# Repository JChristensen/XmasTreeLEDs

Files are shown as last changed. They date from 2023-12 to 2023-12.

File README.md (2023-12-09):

# Xmas Tree LEDs
https://github.com/JChristensen/XmasTreeLEDs  
README file  
Jack Christensen  
Nov-2023

## License
  
Xmas Tree LEDs by Jack Christensen is licensed under a [Creative Commons Attribution-ShareAlike 4.0 International License](http://creativecommons.org/licenses/by-sa/4.0/).

## Overview
Blinkenlights for a small ceramic Christmas Tree. Uses an ATTiny84A microcontroller and a boost regulator to maintain constant voltage to the circuit. Battery is two AAA cells and fits under the base.

See the [firmware here](https://github.com/JChristensen/XmasTree).  
PC boards can be ordered from [OSH Park](https://oshpark.com/shared_projects/T9Cb02lh).  
A bill of materials is available at [Mouser Electronics](https://www.mouser.com/ProjectManager/ProjectDetail.aspx?AccessID=e903af6094) and also in this repo.  

https://github.com/JChristensen/XmasTreeLEDs/assets/762571/b531e305-ae8b-4c04-a3d2-77f9e12bad94

https://github.com/JChristensen/XmasTreeLEDs/assets/762571/8232f8c4-e6b6-4896-a1eb-c29be3a8e65b

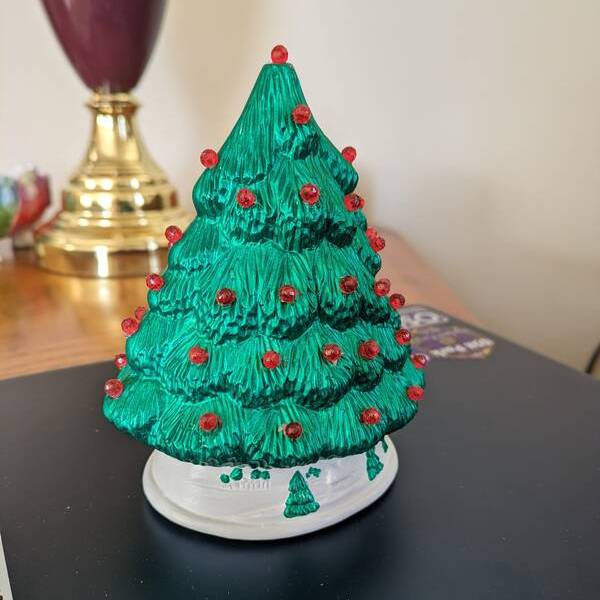
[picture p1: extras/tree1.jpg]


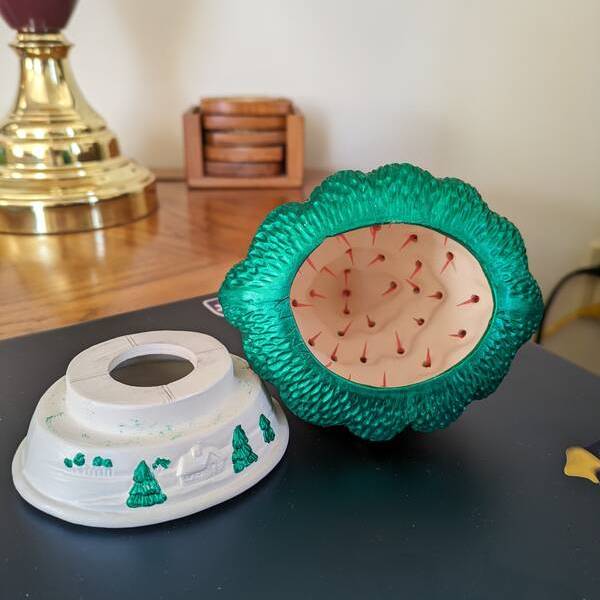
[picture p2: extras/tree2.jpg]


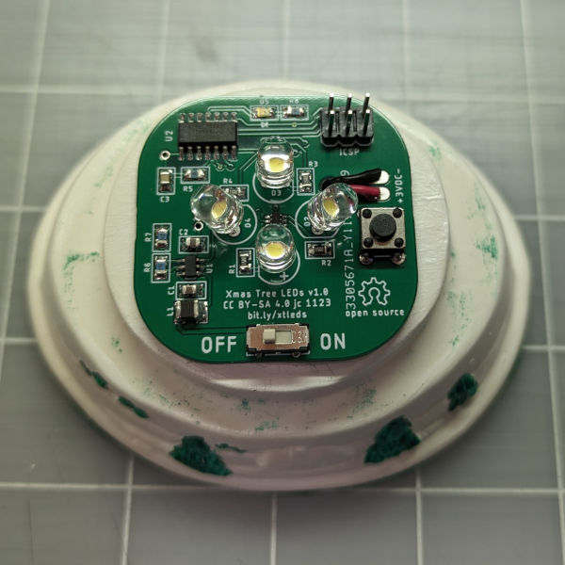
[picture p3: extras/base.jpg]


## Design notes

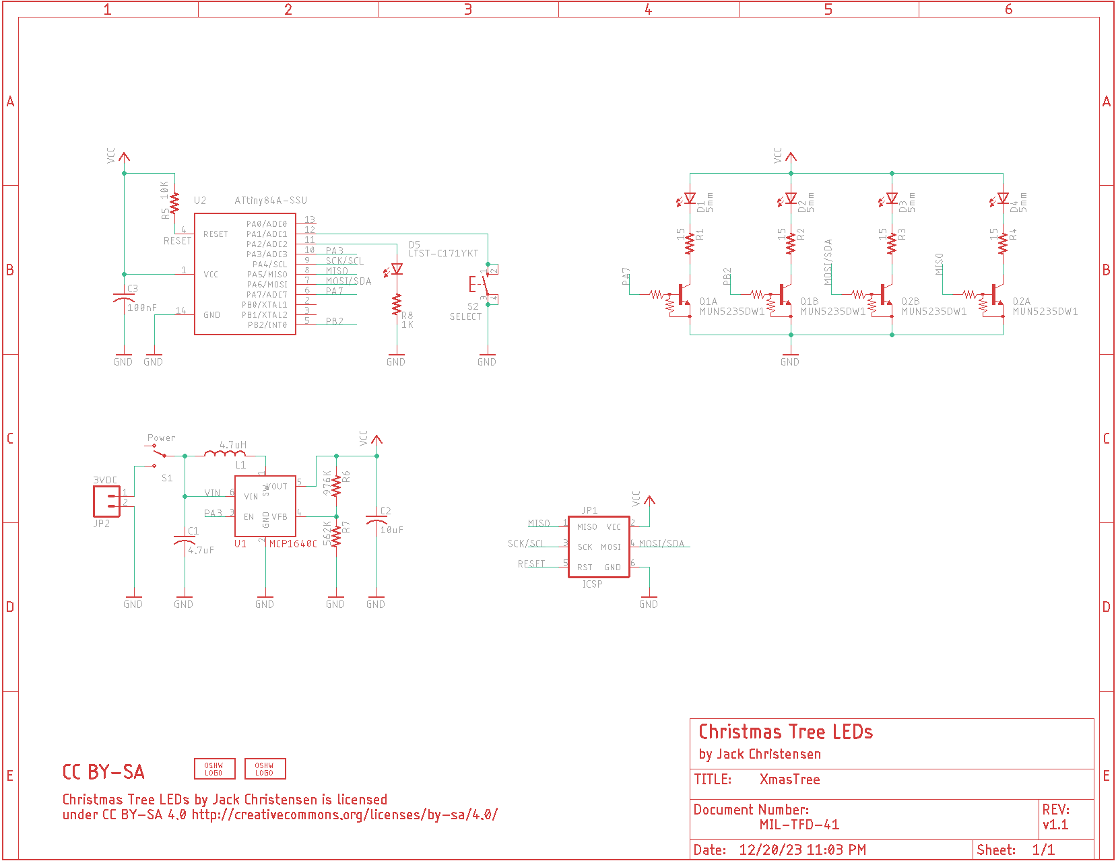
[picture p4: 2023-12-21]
schematic.png

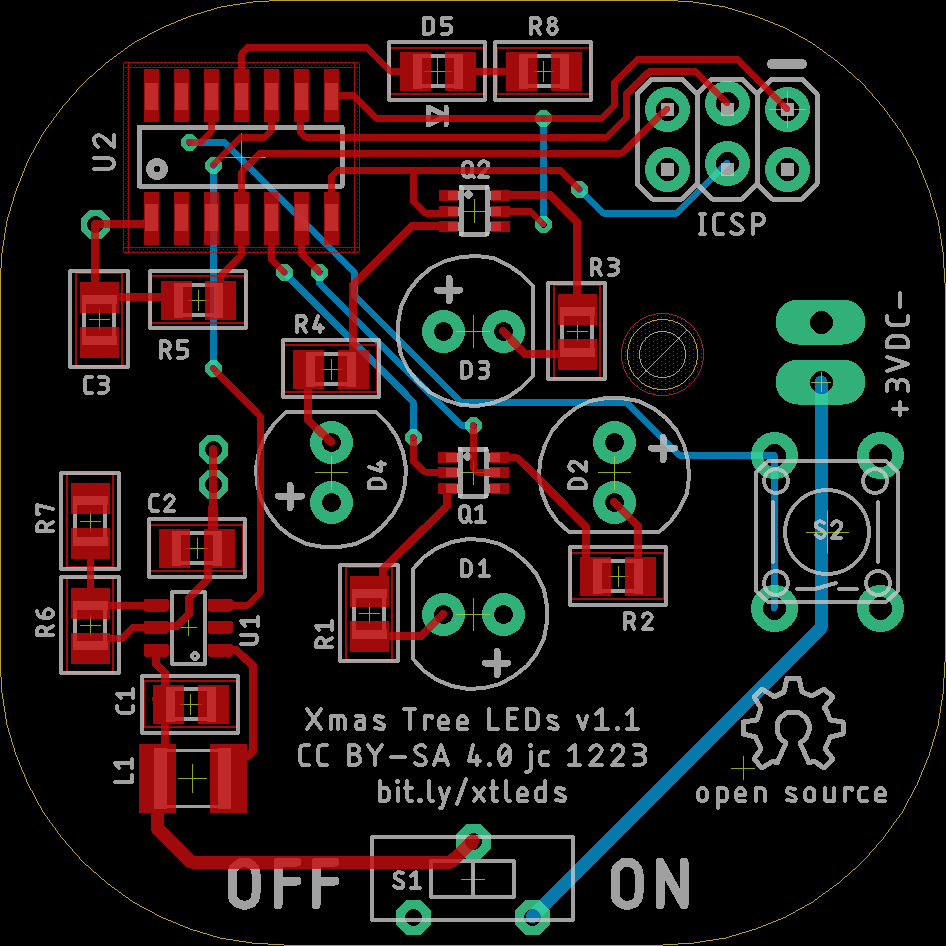
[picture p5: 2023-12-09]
board.png

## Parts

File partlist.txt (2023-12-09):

Partlist

Exported from XmasTree.sch at 12/9/23 4:06 PM

EAGLE Version 9.6.2 Copyright (c) 1988-2020 Autodesk, Inc.

Assembly variant: 

Part     Value          Device                Package        Library  Sheet

B1       2xAAA          Keystone 2489         n/a            n/a      1
C1       4.7uF          C-USM0805             M0805          _jc      1
C2       10uF           C-USM0805             M0805          _jc      1
C3       100nF          C-USM0805             M0805          _jc      1
D1       5mm            LED5MM                LED5MM         _jc      1
D2       5mm            LED5MM                LED5MM         _jc      1
D3       5mm            LED5MM                LED5MM         _jc      1
D4       5mm            LED5MM                LED5MM         _jc      1
D5       LTST-C171YKT   LEDD0805              D0805          _jc      1
JP1      ICSP           AVR_SPI_PRG_62X3_LOCK 2X3_LOCK       _jc      1
JP2      3VDC           M02                   1X02_LONGPADS  SparkFun 1
L1       4.7uH          INDUCTORC1210K        C1210K         _jc      1
Q1       MUN5235DW1T1G  MUN52XXSOT363         SOT363_PHILIPS _jc      1
Q2       MUN5235DW1T1G  MUN52XXSOT363         SOT363_PHILIPS _jc      1
R1       15             R-US_M0805            M0805          _jc      1
R2       15             R-US_M0805            M0805          _jc      1
R3       15             R-US_M0805            M0805          _jc      1
R4       15             R-US_M0805            M0805          _jc      1
R5       10K            R-US_M0805            M0805          _jc      1
R6       976K           R-US_M0805            M0805          _jc      1
R7       562K           R-US_M0805            M0805          _jc      1
R8       1K             R-US_M0805            M0805          _jc      1
S1       Power          SWITCH-SPST           JS102011CQN    SparkFun 1
S2       SELECT         10-XXOCT              B3F-10XXOCT    _jc      1
U1       MCP1640C       MCP1640               SOT23-6        _jc      1
U2       ATtiny84A-SSU  ATTINYX4SO14          SO14           _jc      1

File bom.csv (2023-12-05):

Bill of Materials
Xmas Tree LEDs
by Jack Christensen
Nov-2023
https://www.mouser.com/ProjectManager/ProjectDetail.aspx?AccessID=e903af6094
Part | Qty | Mouser # | Description | Mfr. # | Manufacturer
B1 | 1 | 534-2489 | Cylindrical Battery Contacts, Clips, Holders & Springs 2 AAA cell holder Densi-Pak | 2489 | Keystone Electronics
C1 | 1 | 187-CL21A475KPFNNNE | Multilayer Ceramic Capacitors MLCC - SMD/SMT 4.7uF+/-10% 10V X5R 0805 | CL21A475KPFNNNE | Samsung Electro-Mechanics
C2 | 1 | 187-CL21A106KPCLQNC | Multilayer Ceramic Capacitors MLCC - SMD/SMT 10uF+/-10% 10V X5R 2 0805 | CL21A106KPCLQNC | Samsung Electro-Mechanics
C3 | 1 | 581-08053C104KAT4A | Multilayer Ceramic Capacitors MLCC – SMD/SMT 25V 0.1uF X7R 0805 10% | 08053C104KAT4A | KYOCERA AVX
D1-D4 | 4 | 941-C513AWSNCX0Z0342 | Standard LEDs - Through Hole White | C513A-WSN-CX0Z0342 | Cree LED
D5 | 1 | 859-LTST-C171YKT | Standard LEDs - SMD Yellow Clear 588nm | LTST-C171YKT | Lite-On
JP1 | 1 | 474-PRT-12807 | Header - 2x3 (Male, 0.1") | PRT-12807 | SparkFun Electronics
JP2 | 0 | Board footprint only | Solder pads | n/a | n/a
L1 | 1 | 963-CBC3225T4R7MR | Power Inductors - SMD 1210 4.7uH 130mOhms +/-20% 1010mA HiCur | CBC3225T4R7MR | TAIYO YUDEN
Q1-Q2 | 2 | 863-MUN5235DW1T1G | Bipolar Transistors - Pre-Biased 100mA 50V BRT Dual NPN | MUN5235DW1T1G | onsemi
R1-R4 | 4 | 660-RK73H2ATTD15R0F | Thick Film Resistors - SMD 1/4W 15 OHM 1% | RK73H2ATTD15R0F | KOA Speer
R5 | 1 | 660-RK73H1JTTDD1002F | Thick Film Resistors - SMD 1/10watts 10Kohms 1% | RK73H1JTTDD1002F | KOA Speer
R6 | 1 | 660-RK73H1ETTP9763F | Thick Film Resistors - SMD 0.1watt 976Kohms 1% | RK73H1ETTP9763F | KOA Speer
R7 | 1 | 660-RK73H2ATTD5623F | Thick Film Resistors - SMD 1/4W 562K OHM 1% | RK73H2ATTD5623F | KOA Speer
R8 | 1 | 660-RK73H1JTTDD1001F | Thick Film Resistors - SMD 1/8watts 1Kohms 1% | RK73H1JTTDD1001F | KOA Speer
S1 | 1 | 611-JS102011CQN | Slide Switches Sub-Miniature Slide Switch | JS102011CQN | C&K Switches
S2 | 1 | 653-B3F-1020 | Tactile Switches 6X6 Flat 5mm Btn Force 100g w/o Grd | B3F-1020 | Omron
U1 | 1 | 579-MCP1640CT-I/CHY | Switching Voltage Regulators 500 kHz 300 mA Syn Boost Converter | MCP1640CT-I/CHY | Microchip
U2 | 1 | 556-ATTINY84A-SSU | 8-bit Microcontrollers - MCU 20MHz Ind. Grade | ATTINY84A-SSU | Microchip

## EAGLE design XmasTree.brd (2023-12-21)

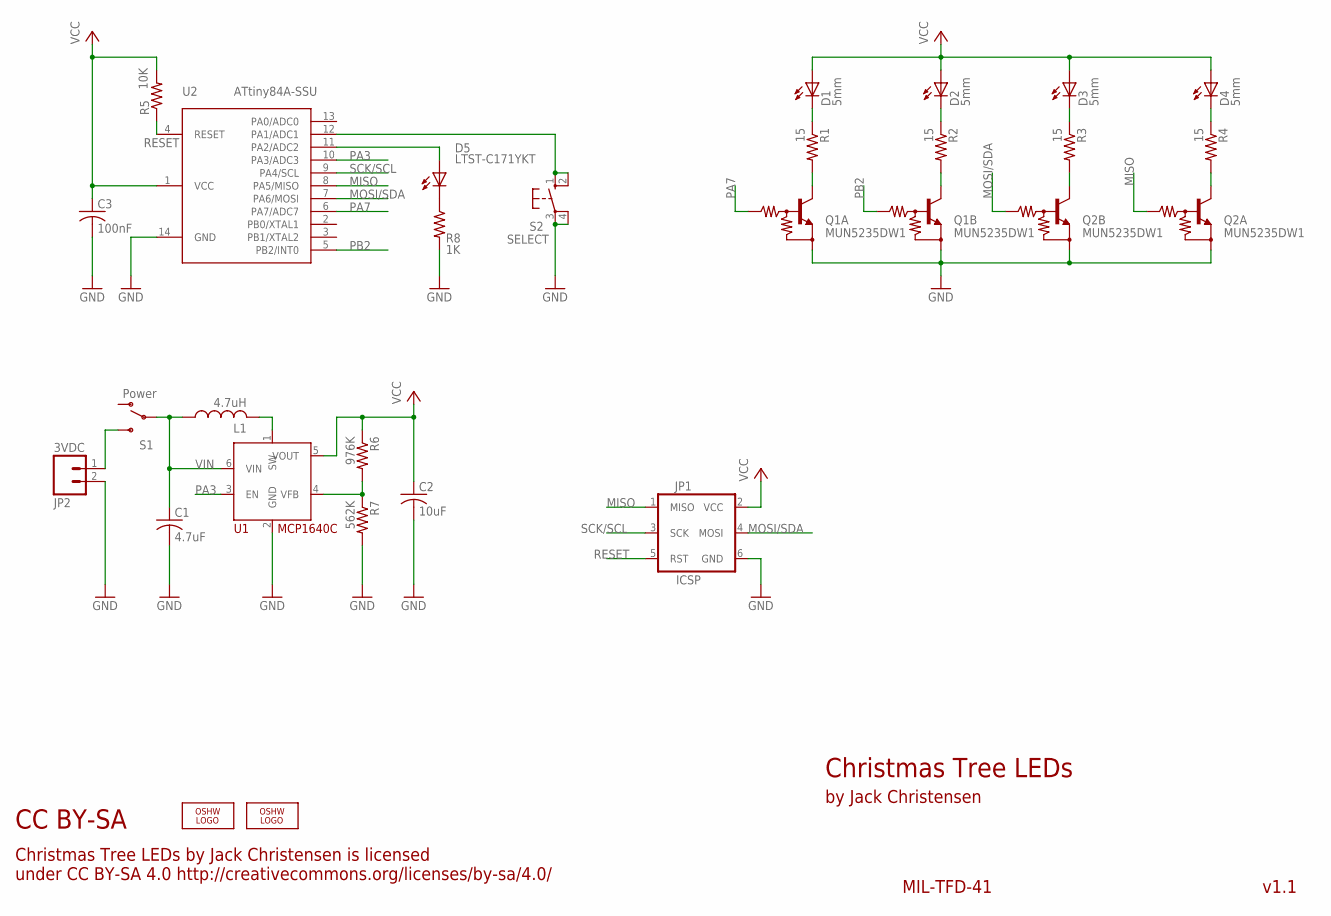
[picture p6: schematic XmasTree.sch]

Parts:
C1: 4.7uF; M0805
C2: 10uF; M0805
C3: 100nF; M0805
D1, D2, D3, D4: 5mm; LED5MM
D5: LTST-C171YKT; D0805
JP1: ICSP; 2X3_LOCK
JP2: 3VDC; 1X02_LONGPADS
L1: 4.7uH; C1210K
LOGO1, LOGO2: OSHW_LOGO_8MILX0150-NT; OSHW_8X150_NOTEXT
Q1, Q2: MUN5235DW1; SOT363_PHILIPS
R1, R2, R3, R4: 15; M0805
R5: 10K; M0805
R6: 976K; M0805
R7: 562K; M0805
R8: 1K; M0805
S1: Power; JS102011CQN
S2: SELECT; B3F-10XXOCT
U1: MCP1640C; SOT23-6
U2: ATtiny84A-SSU; SO14

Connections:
GND: C1.2, C2.2, C3.2, JP1.6 (GND), JP2.2, Q1.1 (E), Q1.4 (E), Q2.1 (E), Q2.4 (E), R7.2, R8.2, S2.3, S2.4 (P1), U1.2 (GND), U2.14 (GND)
MISO: JP1.1 (MISO), Q2.5 (B), U2.8 (PA5/MISO)
MOSI/SDA: JP1.4 (MOSI), Q2.2 (B), U2.7 (PA6/MOSI)
unnamed: D1.K (C), R1.1
unnamed: R6.2, R7.1, U1.4 (VFB)
unnamed: D2.K (C), R2.1
unnamed: Q2.6 (C), R3.2
unnamed: Q1.3 (C), R1.2
unnamed: JP2.1, S1.P$3 (S)
unnamed: L1.2, U1.1 (SW)
unnamed: Q1.6 (C), R2.2
unnamed: Q2.3 (C), R4.2
unnamed: D5.K (C), R8.1
unnamed: D5.A, U2.11 (PA2/ADC2)
unnamed: S2.1 (S), S2.2 (S1), U2.12 (PA1/ADC1)
unnamed: D4.K (C), R4.1
unnamed: D3.K (C), R3.1
PA3: U1.3 (EN), U2.10 (PA3/ADC3)
PA7: Q1.5 (B), U2.6 (PA7/ADC7)
PB2: Q1.2 (B), U2.5 (PB2/INT0)
RESET: JP1.5 (RST), R5.1, U2.4 (RESET)
SCK/SCL: JP1.3 (SCK), U2.9 (PA4/SCL)
VCC: C2.1, C3.1, D1.A, D2.A, D3.A, D4.A, JP1.2 (VCC), R5.2, R6.1, U1.5 (VOUT), U2.1 (VCC)
VIN: C1.1, L1.1, S1.P$2, U1.6 (VIN)

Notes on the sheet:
Christmas Tree LEDs
by Jack Christensen
Christmas Tree LEDs by Jack Christensen is licensed under CC BY-SA 4.0 http://creativecommons.org/licenses/by-sa/4.0/
CC BY-SA
v1.1
MIL-TFD-41

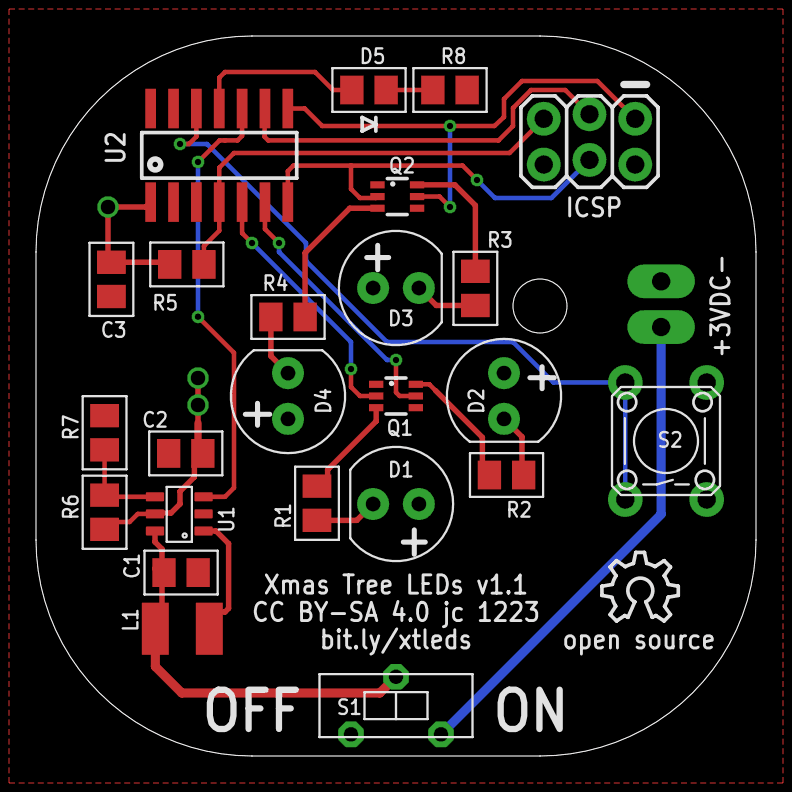
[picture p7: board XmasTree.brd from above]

Board: 2 copper layers, 40.0 x 40.0 mm, 27 parts (1 on the bottom side), 24 nets.

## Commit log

2023-11-28 Initial commit.
    [XmasTree.brd, XmasTree.sch]
2023-11-28 Add select button.
    [XmasTree.brd, XmasTree.sch]
2023-11-28 Add BOMs.
    [bom.csv, bom.ods]
2023-12-05 Update LED dropping resistor values.
    [XmasTree.brd, XmasTree.sch, bom.csv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]
2023-12-09 Board tweaks.
    [XmasTree.brd, XmasTree.sch]
2023-12-21 Cosmetic tweaks to schematic.
    [XmasTree.brd, XmasTree.sch]
2023-12-21 Update schematic image file.

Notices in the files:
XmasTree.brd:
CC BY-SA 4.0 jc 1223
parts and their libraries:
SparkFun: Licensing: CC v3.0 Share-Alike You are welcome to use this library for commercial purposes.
